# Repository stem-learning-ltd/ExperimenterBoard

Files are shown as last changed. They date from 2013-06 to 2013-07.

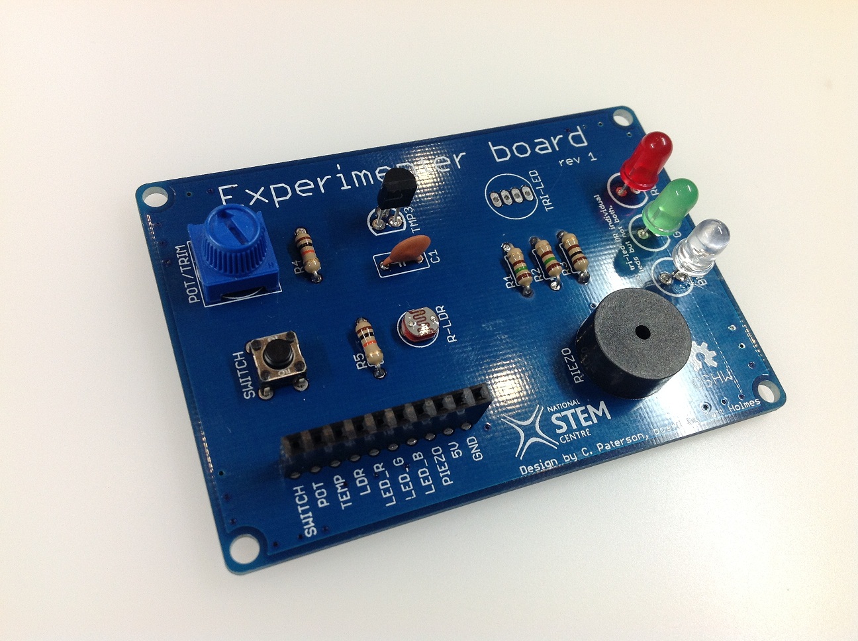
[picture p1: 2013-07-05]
Images/ExpBoard_built.jpg

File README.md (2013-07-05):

Arduino experimenter board
==========================

The concept of this board was developed by C. Paterson to complement an Arduino board for an introduction to "physical computing" at a York CAS Hub meeting at the [National STEM Centre](http://www.nationalstemcentre.org.uk "National STEM Centre website").

The board design and all design files are released under a [Creative Commons Attribution ShareAlike license](http://creativecommons.org/licenses/by-sa/3.0/).

The PCBs were produced by [Hackvana](http://www.hackvana.com "Hackvana website")

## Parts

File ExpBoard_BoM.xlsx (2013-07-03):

Bill of materials
ID | Desc | Make/model | Supplier | Code
R1 | Red LED current limiting resistor | 150R 0.25W | Farnell | 9339175
R2 | Green LED current limiting resistor | 150R 0.25W | Farnell | 9339175
R3 | Blue LED current limiting resistor | 100R 0.25W | Farnell | 9339043
R4 | Switch pullup resistor | 10K 0.25W | Farnell | 9339060
R5 | LDR potential divider resistor | 10K 0.25W | Farnell | 9339060
C1 | Decoupling capacitor | 0.1UF, 50V, Y5V | Farnell | 9411887
R-LDR | Light dependant resistor |  | CPC | RE04698
PIEZO | Piezo transducer (speaker) | 5V, 1mA | CPC | LS03781
TRI-LED | Tri-colour LED common cathode |  | eBay
TMP36 | Analog temperature sensor | TMP36GT9Z | Farnell | 1438760
POT | Variable resistor | 10K | Farnell | 9608230
SWITCH | PCB mount switch | Tactile | CPC | 1960939
HEADER | 0.1" Pin header | 10way, 1 row, Socket | CPC | CN14535
RED | Red LED 5mm | T1 3/4, 20mA, 2V | Farnell | 1461624
GRN | Green 5mm LED | T1 3/4, 20mA, 2V | Farnell | 1461633
BLUE | Blue 5mm LED | T1 3/4, 20mA, 3.2V | Farnell | 1855507

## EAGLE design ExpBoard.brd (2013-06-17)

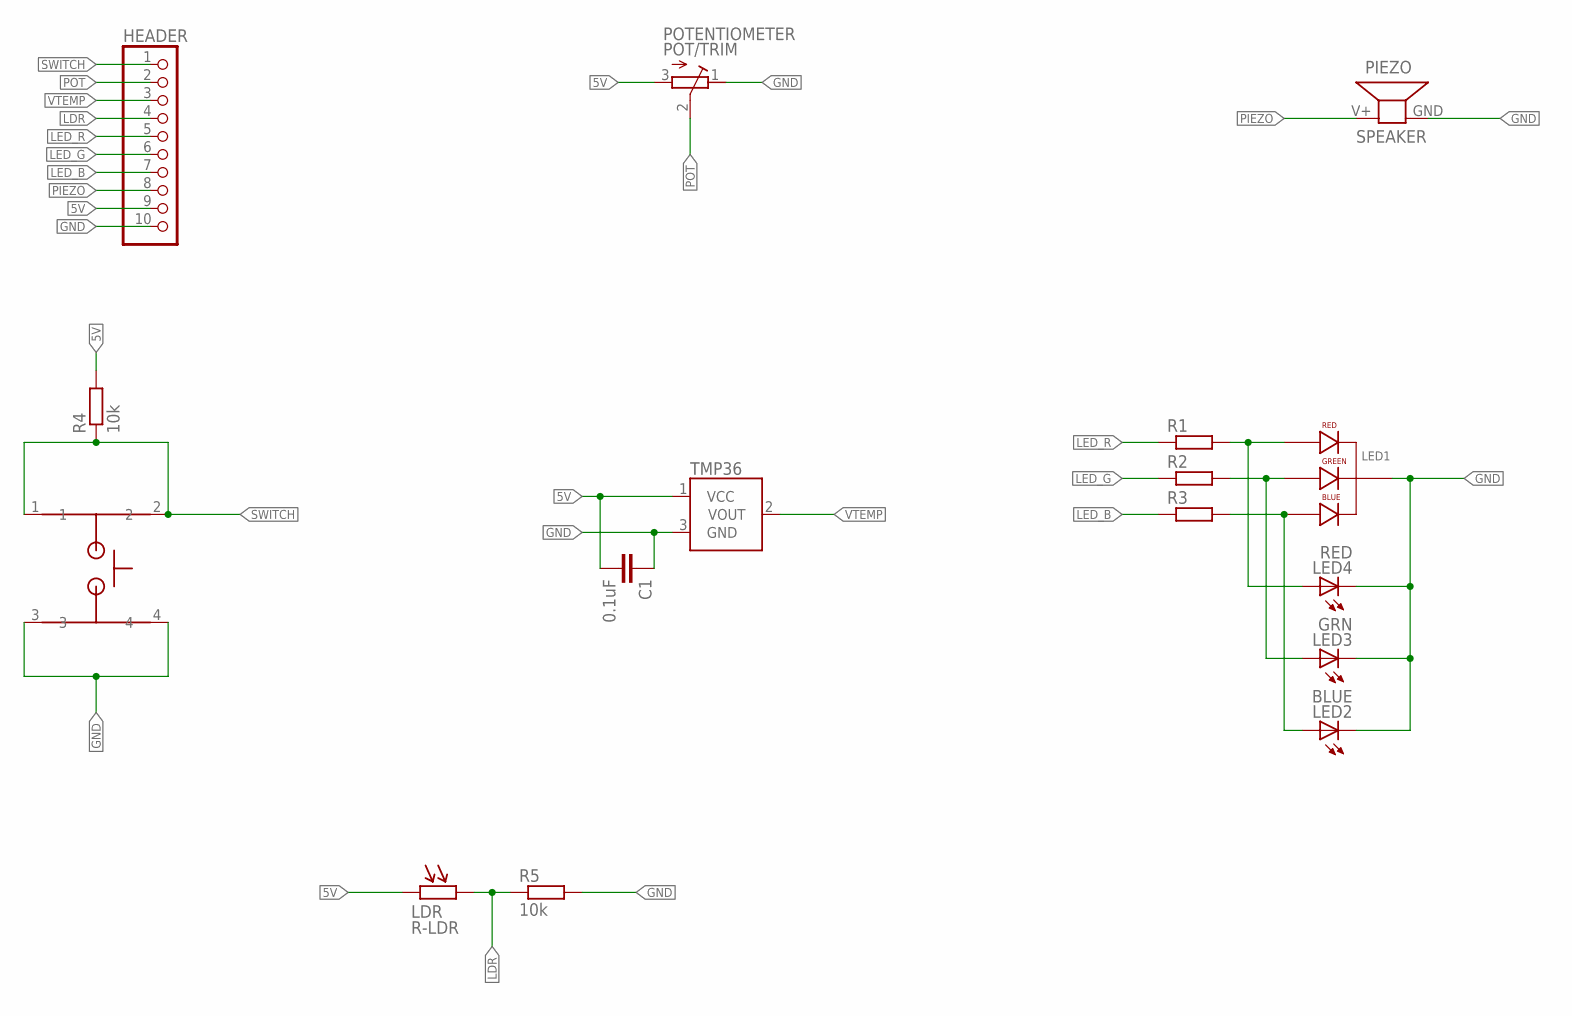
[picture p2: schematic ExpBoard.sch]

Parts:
C1: 0.1uF; C050-035X075
HEADER: PINHD-1X10; 1X10
LDR: R-LDR; LDR_RE04698
LED1: LED; LED-RGB-TH
LED2: BLUE; LED5MM
LED3: GRN; LED5MM
LED4: RED; LED5MM
PIEZO: SPEAKER; PIEZO_LS03781
POTENTIOMETER: POT/TRIM; TRIM_RE06540
R1, R2, R3: R-EU_0204/7; 0204/7
R4, R5: 10k; 0204/7
SWITCH: SWITCH; SKHHAMA010
TMP36: TMP36GT9; TO-92

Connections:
5V: C1.2, HEADER.9, LDR.1, POTENTIOMETER.3 (E), R4.2, TMP36.1 (VCC)
GND: C1.1, HEADER.10, LED1.3 (CATHODE), LED2.K (C), LED3.K (C), LED4.K (C), PIEZO.GND (2), POTENTIOMETER.1 (A), R5.2, SWITCH.3, SWITCH.4, TMP36.3 (GND)
LDR: HEADER.4, LDR.2, R5.1
LED_B: HEADER.7, R3.1
LED_G: HEADER.6, R2.1
LED_R: HEADER.5, R1.1
unnamed: LED1.4 (RED_ANODE), LED4.A, R1.2
unnamed: LED1.2 (GREEN_ANODE), LED3.A, R2.2
unnamed: LED1.1 (BLUE_ANODE), LED2.A, R3.2
PIEZO: HEADER.8, PIEZO.V+ (1)
POT: HEADER.2, POTENTIOMETER.2 (S)
SWITCH: HEADER.1, R4.1, SWITCH.1, SWITCH.2
VTEMP: HEADER.3, TMP36.2 (VOUT)

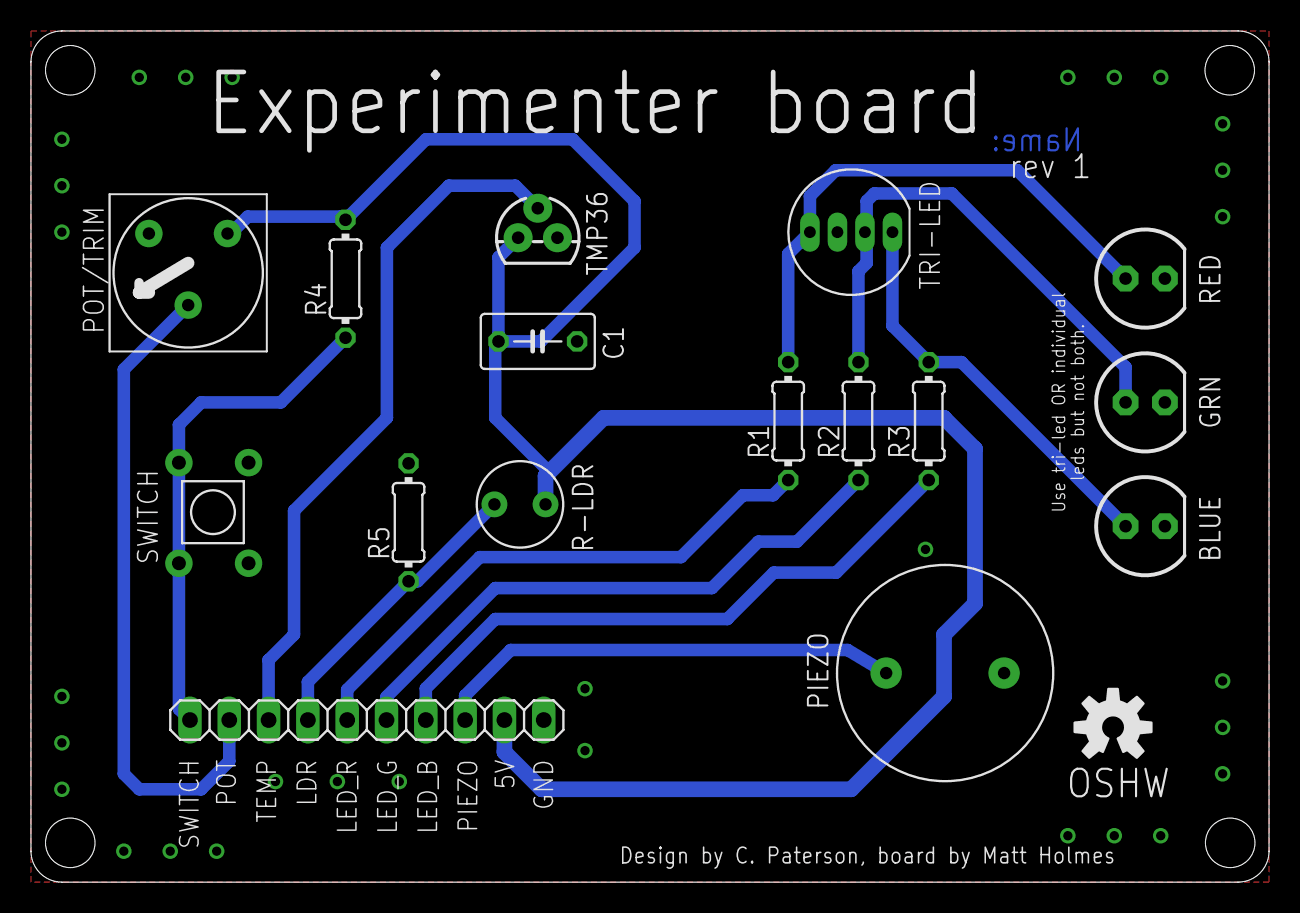
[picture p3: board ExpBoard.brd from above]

Board: 2 copper layers, 80.0 x 55.0 mm, 18 parts (0 on the bottom side), 13 nets.

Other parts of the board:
U$1: OSHW-LOGO-M
U$2: OSHW-LOGO-L

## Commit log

2013-06-17 Initial commit
    Revision 1 board complete
    [ExpBoard.brd, ExpBoard.sch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]
2013-06-17 Added initial BoM and README
    [ExpBoard_BoM.xlsx]
2013-07-03 Updates BoM with exact components used
    [ExpBoard_BoM.xlsx]
2013-07-05 Added image of completed board

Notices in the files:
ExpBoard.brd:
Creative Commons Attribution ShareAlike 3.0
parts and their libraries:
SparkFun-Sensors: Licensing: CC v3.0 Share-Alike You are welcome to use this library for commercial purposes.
